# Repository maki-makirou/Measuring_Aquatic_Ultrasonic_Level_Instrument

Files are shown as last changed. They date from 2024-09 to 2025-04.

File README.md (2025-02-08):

# [Measuring Aquatic Ultrasonic Level Instrument (MAULI)](https://github.com/maki-makirou/Measuring_Aquatic_Ultrasonic_Level_Instrument)
Raspberry Pi Pico を用いた電子工作による**安価で高性能なロガー付き超音波式水位計**です。（1台約6,000円で作成できます。）　プログラムや部品を自由に変更して改造を楽しむことができます。

This is a low-cost, high-performance ultrasonic water level meter with logger that is electronically built using Raspberry Pi Pico. (One can be made for about 6,000 yen.) You can freely change the program and parts to have fun modifying it.

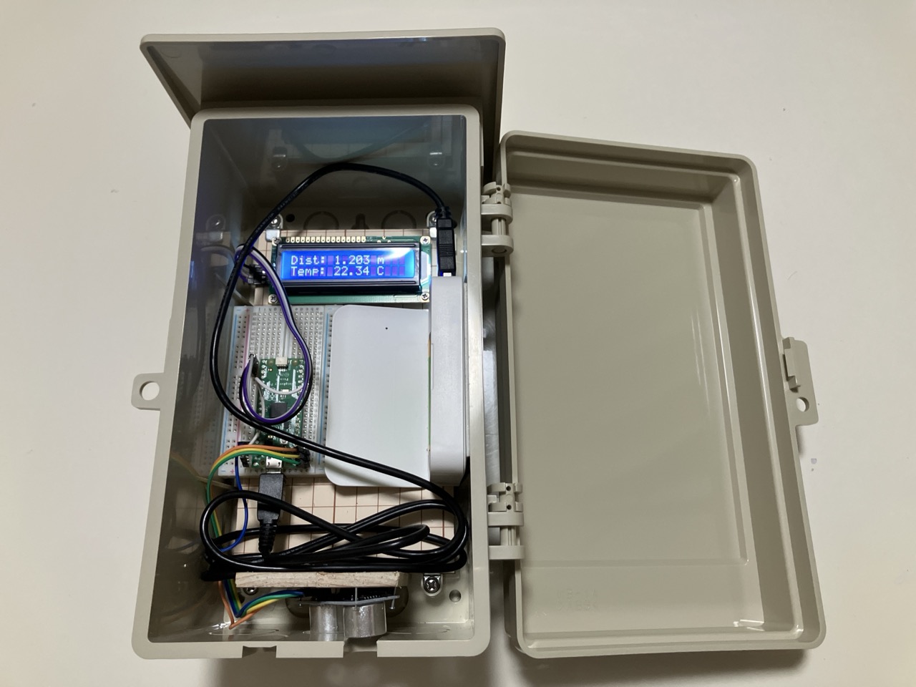
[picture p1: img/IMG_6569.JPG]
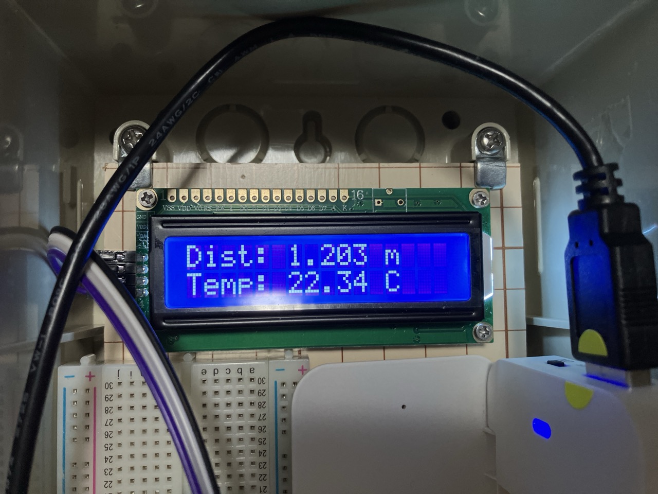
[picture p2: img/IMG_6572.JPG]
　　

<br>

## 特徴
- 主要コードは MicroPython で書かれたプログラマブル水位計です。目的に応じて測定間隔など様々なパラメータを変更することができます。プログラム自体も自由に変更できます。
- 1台約6,000円と安価に作成できます。（部品の送料、消耗品、工具等の費用を除く）
- Raspberry Pi Pico 内のメモリをロガーとしてcsv形式で計測値（水面までの距離、気温）を記録することができます。
- 超音波センサー（HC-SR04）の性能に基づき、0.3cm 程度の分解能の計測が可能です。（測定距離min: 0.02m、測定距離max: 4.5m、動作温度min: -10℃、動作温度max: 70℃、有効角度： 15度）　また、超音波の速度について Raspberry Pi Pico の内蔵温度計を使った温度補正を行っています。
- 超音波センサーを小型プラボックスに格納するため屋外での計測が可能です。雨天時の計測もできます。
- 故障した場合でも部品単位で修理が可能です。
- 異常値が出た時に自動的に設定した時間間隔、回数で再計測させることができます。
- 水位計測しない時間は lightsleep 状態となるため比較的長期間の連続観測が可能です。初期設定値（計測間隔1分、再計測最大2回、再計測10秒後）において、アルカリ単3電池3本で約5.2日間の連続計測ができます。アルカリ単1電池6本仕様に改造すれば約2ヶ月間（約59.6日間）の連続計測ができる見込みです。

<br>

## 短所
- 耐久性はあまりないと思われます。
- DIY水位計のため、組み立てが面倒です。
- 最大測定距離が4.5mしかないため、大河川などには向きません。
- 超音波センサーの有効角度が15度であるため、複雑な横断形状の小水路などには向きません。（センサーが水面以外の反射を拾ってしまうため）
- RTCを使用していないため日時が記録されません。記録開始日時をメモしてデータ回収後、自分で日時補正する必要があります。
- 超音波センサーから水面までの計測距離がロガーに記録されるため、自分で水位に変換する必要があります。
- 水位計の設置位置によってはノイズが出ることがあります。（設置やパラメータの変更で改善させることができます。）　一方、大雨時はノイズが出にくいので高水観測に向いています。
- 使用部品の仕様が変更された場合、正しく動作させるために配線やコードの修正が必要になる可能性があります。

<br>

## ライセンス
- 作者が作成した python コードは MIT ライセンスに従って自由に改変することが出来ます。
- 作者以外の方が作成したコードについては、以下の通り各作者の主張するライセンスに従う必要があります。
  - 内蔵温度計から温度を取得する[コード](https://github.com/raspberrypi/pico-micropython-examples/blob/master/adc/temperature.py)の著作権は Raspberry Pi Ltd. にあります。ライセンスは [LICENSE.txt](https://github.com/raspberrypi/pico-micropython-examples/blob/master/LICENSE.txt)に従う必要があります。
  - LCD関係のコードの著作権は Tyler Peppy(T-622) 氏にあります。https://github.com/T-622/RPI-PICO-I2C-LCD
  - 超音波センサーの値取得に関するコードは広く使われているものですが出典が不明です。自己責任でご使用ください。情報をお持ちの方は [Discussions](https://github.com/maki-makirou/Measuring_Aquatic_Ultrasonic_Level_Instrument/discussions) にお願いします。

<br>

## 作り方
以下のリンク先をご覧ください。
- [2025年1月版](https://github.com/maki-makirou/Measuring_Aquatic_Ultrasonic_Level_Instrument/blob/main/MAULI_202501/MAULI_202501.md)

<br>

## 使い方
### 設置時
1. **水位観測における失敗の殆どが水位計の設置ミスに起因**するものです。予め十分に練習してコツを掴んでおいてください。
- **超音波の有効角度が15度であることを踏まえ、超音波が不要なもの（構造物や植物等）に当たらないように（水面だけに当たるように）水位計を設置**してください。
- **水位計は水深が変化しない地点に設置**してください。

2. 初期設定では、**電源を入れて1分間は計測値が液晶ディスプレイに表示されるスタートモード**になり、**1分後以降はログ記録モードになり測定値を内部メモリに1分間隔で記録します**。電池をセットし、時計を見ながら 00 秒ちょうどに電源を入れてください。**1分後の時刻を忘れずにメモしてください。**

3. **水位計の設置地点の水深をmm単位で測り、忘れずにメモしておいてください。**

4. 屋外で使用する場合は、風等の衝撃で電池が外れることがあります。**電池が外れないように必ずセロハンテープ等で固定してください。**

5. **南京錠等でフタが開かないようにしてください。**

<br>

### データ回収時
1. 水位計を回収したら　PC に接続して Thonny を起動して、右上の「STOP」ボタンを押した後、ラズパイ pico 内の「log.csv」ファイルを開いてデータをコピーしてください。Thonny の使い方は他のサイトで調べてください。

2. 表計算ソフトを立ち上げてコピーしたデータをペーストして一旦保存してください。

3. メモした記録開始時間と水深データを使って、水位の時刻変化のデータに変換してください。ロガーに記録されている 「Distance(m)」 は超音波センサー先端から水面までの距離を記録したものですので水位への変換が必要です。

4. 無事にデータを水位に変換できたら、次の測定のために Thonny でラズパイ pico 内の「log.csv」ファイルを右クリックして「Delete」してください。

<br>

## 改造について
大容量の電池を使用できるようになればより実用的になります。[このサイト（単1電池6本版）](https://github.com/maki-makirou/Measuring_Aquatic_Ultrasonic_Level_Instrument_Mod)をご参考ください。
また、水位計を wifi 対応にしてIoT機器化したい場合は、[このサイト](https://github.com/maki-makirou/RPI-RP2_genkan_mimamoru_kun)のコードが参考になるかもしれません。
他にもSDカード対応にしたり、ソーラー電源を付けたり、Bluetooth対応にしたり、アイディア次第で様々な発展形が考えられます。
なお、改造についても自己責任となりますので、リスクを理解した上で楽しんでください。

<br>

## 注意点
屋外設置の際は、土地所有者や水路管理者の許可が必要です。**許可なく水位計を設置しないようご注意ください。**

<br>

## ノウハウ
使用上のノウハウを[ここ](https://github.com/maki-makirou/Measuring_Aquatic_Ultrasonic_Level_Instrument/blob/main/Know-how/Know-how.md)にまとめました。

<br>

## 問い合わせ先
  [Discussions](https://github.com/maki-makirou/Measuring_Aquatic_Ultrasonic_Level_Instrument/discussions) で問い合わせてください。

<br>

## 謝辞
Raspberry Pi財団の皆様と電子部品やプラボックス等を供給してくださるメーカーの皆様に感謝します。最後に私の妻に感謝します。

<br>

## 履歴
- 2024-12-22 公開

<br>

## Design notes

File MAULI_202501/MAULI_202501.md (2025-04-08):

# Measuring Aquatic Ultrasonic Level Instrument (MAULI) の作り方 (2025年1月版)
Raspberry Pi Pico を用いた電子工作による安価で高性能なロガー付き超音波式水位計の作り方です。

<br>

## 部品等
### 部品リスト
使用した部品と購入先のリンクをまとめました。**一見同じ製品に見えても仕様が異なるものがあります。リンク先のものを購入することを強くおすすめします。**

|No|購入先|部品名（購入先リンク）|価格|確認年月|備考|
|---|---|---|---:|---|---|
|1|スイッチサイエンス|[Raspberry Pi Pico H](https://www.switch-science.com/collections/raspberry-pi/products/8170)|¥1,012|2024/10||
|2|秋月電子通商|[HC-SR04　超音波センサー](https://akizukidenshi.com/catalog/g/g111009/)|¥300|2024/10|2020年型であること|
|3|秋月電子通商|[ブレッドボード BB-801](https://akizukidenshi.com/catalog/g/g105294/)|¥220|2024/10||
|4|秋月電子通商|[USBケーブル USB2.0 Aオス-マイクロBオス 1.5m A-microB](https://akizukidenshi.com/catalog/g/g107607/)|¥170|2024/10||
|5|Amazon|[Freenove I2C LCD 1602モジュール、新しいタイプIIC TWIシリアル16x2ディスプレイ](https://www.amazon.co.jp/Freenove-1602%E3%83%A2%E3%82%B8%E3%83%A5%E3%83%BC%E3%83%AB%E3%80%81%E6%96%B0%E3%81%97%E3%81%84%E3%82%BF%E3%82%A4%E3%83%97IIC-TWI%E3%82%B7%E3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)|¥1,080|2024/10|新型であること。2個入りの方が安いです。|
|6|Amazon|[未来工業(MIRAI) ウオルボックス 屋根付・タテ型 有効フカサ90 ベージュ 1個 WB-1AJ](https://www.amazon.co.jp/%E6%9C%AA%E6%9D%A5%E5%B7%A5%E6%A5%AD-%E3%82%A6%E3%82%AA%E3%83%AB%E3%83%9C%E3%83%83%E3%82%AF%E3%82%B9-%E5%B1%8B%E6%A0%B9%E4%BB%98%E3%83%BB%E3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)|¥1,835|2024/10|[楽天市場でも購入できます](https://item.rakuten.co.jp/denzaido/4571359794828/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)|
|7|Amazon|[KKHMF 3PCS 120本 20cm ブレッドボード・ジャンパーワイヤ 回路基板のジャンパーピン（メス-オス）](https://www.amazon.co.jp/KKHMF-40%E6%9C%AC-20cm-%E3%83%96%E3%83%AC%E3%83%83%E3%83%89%E3%83%9C%E3%83%BC%E3%83%89%E3%83%BB%E3%82%B8%E3%83%A3%E3%83%B3%E3%83%91%E3%83%BC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)|¥699|2024/10|※1|
|8|Amazon|[3M 両面テープ 超強力 スーパー多用途 幅12mm 長さ4m スコッチ SPS-12 セミロング プレミアゴールド](https://www.amazon.co.jp/3M-%E3%82%B9%E3%83%AA%E3%83%BC%E3%82%A8%E3%83%A0-SPS-12-%E3%82%B9%E3%82%B3%E3%83%83%E3%83%81%E8%B6%85%E5%BC%B7%E5%8A%9B%E4%B8%A1%E9%9D%A2%E3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)|¥752|2024/10|※1|
|9|Amazon|[ボンド ウルトラ多用途S・U プレミアムソフト クリヤー 25ml](https://www.amazon.co.jp/%E3%82%A6%E3%83%AB%E3%83%88%E3%83%A9%E5%A4%9A%E7%94%A8%E9%80%94S%E3%83%BBU-%E3%83%97%E3%83%AC%E3%83%9F%E3%82%A2%E3%83%A0%E3%82%BD%E3%83%95%E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)|¥584|2024/10|※1|
|10|ヒラキ|[乾電池式モバイルバッテリー](https://www.hiraki.co.jp/ec/pro/disp/1/53128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)|¥638|2024/10||
|11|スーパービバホーム|桧工作材　5x30x900|¥408|2024/10|最終的に必要なサイズは 5x60x80 です。[写真](https://github.com/maki-makirou/Measuring_Aquatic_Ultrasonic_Level_Instrument/blob/main/MAULI_202501/Woodworking/img/IMG_4892.JPG)　※1|
|12|スーパービバホーム|ピン釘（20x13mm）|¥138|2024/11|[写真](https://github.com/maki-makirou/Measuring_Aquatic_Ultrasonic_Level_Instrument/blob/main/MAULI_202501/Woodworking/img/IMG_6449.JPG)　※1|
|13|スーパービバホーム|ステンレス建具用木ねじ皿（2x19mm）|¥228|2024/11|[写真](https://github.com/maki-makirou/Measuring_Aquatic_Ultrasonic_Level_Instrument/blob/main/MAULI_202501/Woodworking/img/IMG_6419.JPG)　※1|
|14|スーパービバホーム|ピン釘（20x19mm）|¥138|2024/11|[写真](https://github.com/maki-makirou/Measuring_Aquatic_Ultrasonic_Level_Instrument/blob/main/MAULI_202501/Woodworking/img/IMG_6335.JPG)　※1|

<br>

※1 量が多いので、2台目以降を製作する場合は当分の間、追加購入は不要です。1台目製作時は購入してください。

<br>

#### ！！！　注意点　！！！
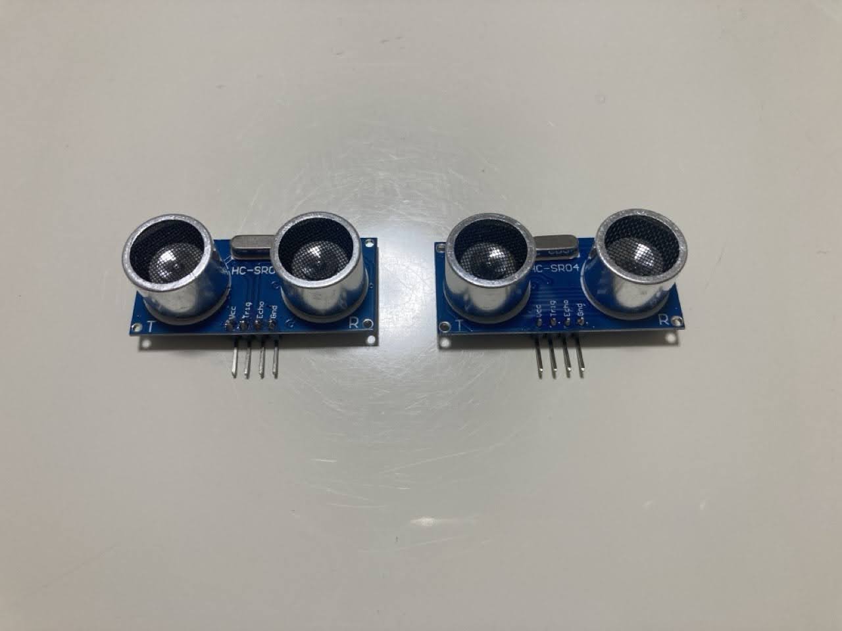
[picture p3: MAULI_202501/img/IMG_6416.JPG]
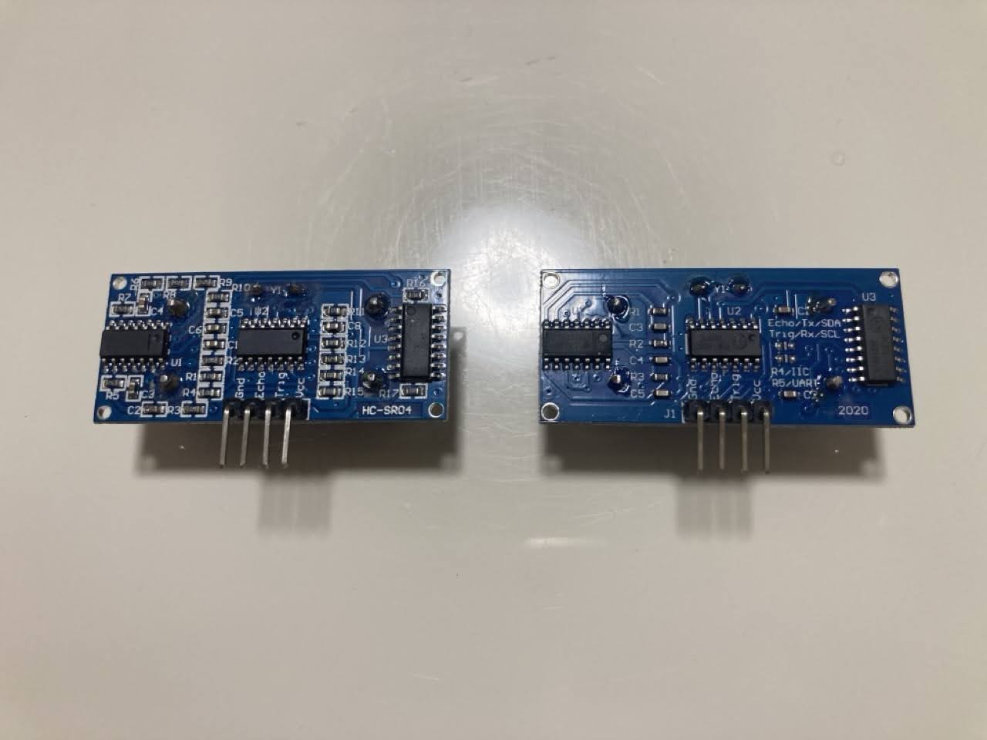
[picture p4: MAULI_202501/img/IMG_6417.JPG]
　　

超音波センサーについて、右側が3.3V仕様の2020年型です。左側は5V仕様のもので今回の配線では動きません。似ているのでご注意ください。リンク先のものを購入することをおすすめします。

<br>

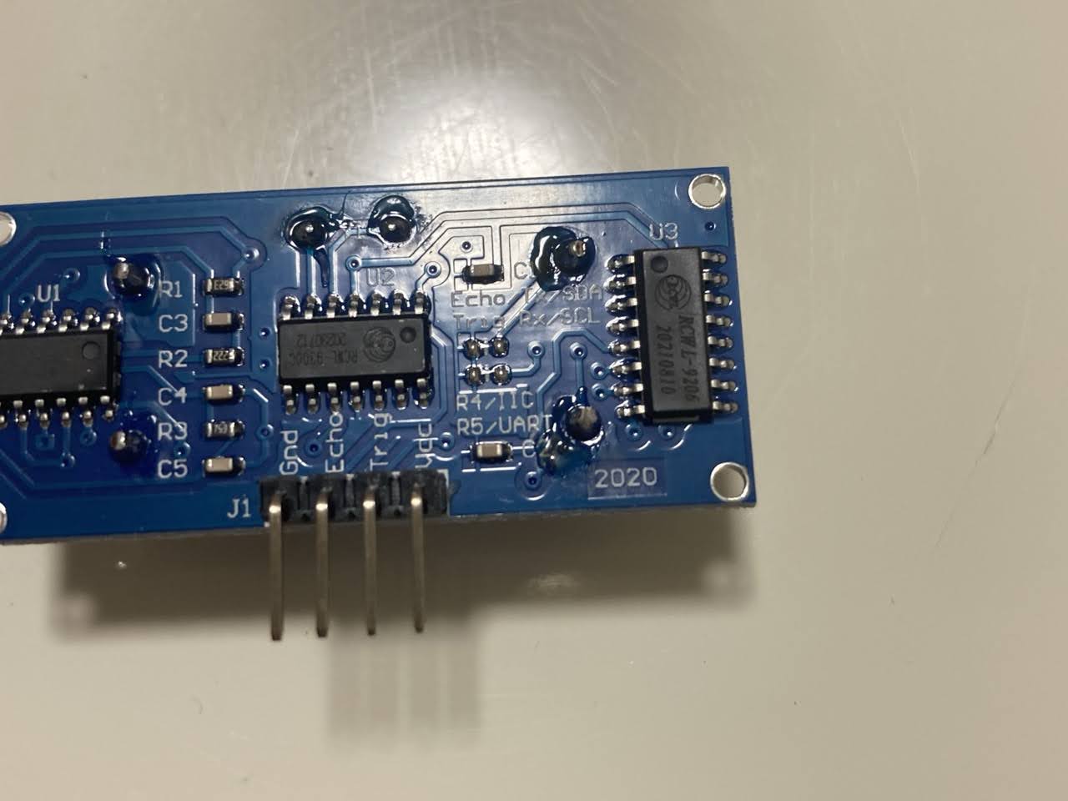
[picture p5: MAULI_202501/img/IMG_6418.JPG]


2020年型は基板の右下に「2020」がプリントされています。
もし、5V仕様のものを間違えて購入した場合は、例えば[この配線図](https://github.com/maki-makirou/Measuring_Aquatic_Ultrasonic_Level_Instrument/blob/main/MAULI_202501/img/202210_B.png)
のようにして、下の方にある[このコード](https://github.com/maki-makirou/Measuring_Aquatic_Ultrasonic_Level_Instrument/blob/main/MAULI_202501/MAULI_20250113.py)の一部を上段から下段に変えると使用できます。

```
# Old
trigger = Pin(0, Pin.OUT)
echo = Pin(1, Pin.IN)
led = Pin(25, Pin.OUT)
i2c = I2C(0, sda = Pin(16), scl = Pin(17), freq = 400000)
```

```
# New
trigger = Pin(14, Pin.OUT)
echo = Pin(15, Pin.IN)
led = Pin(25, Pin.OUT)
i2c = I2C(0, sda = Pin(0), scl = Pin(1), freq = 400000)
```

<br>

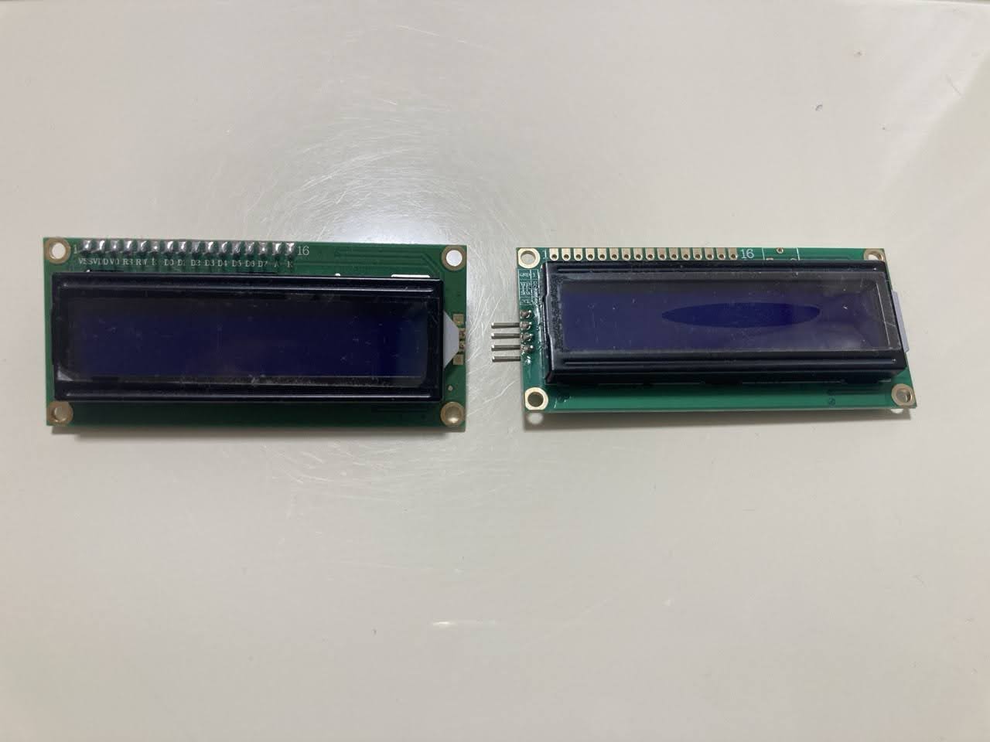
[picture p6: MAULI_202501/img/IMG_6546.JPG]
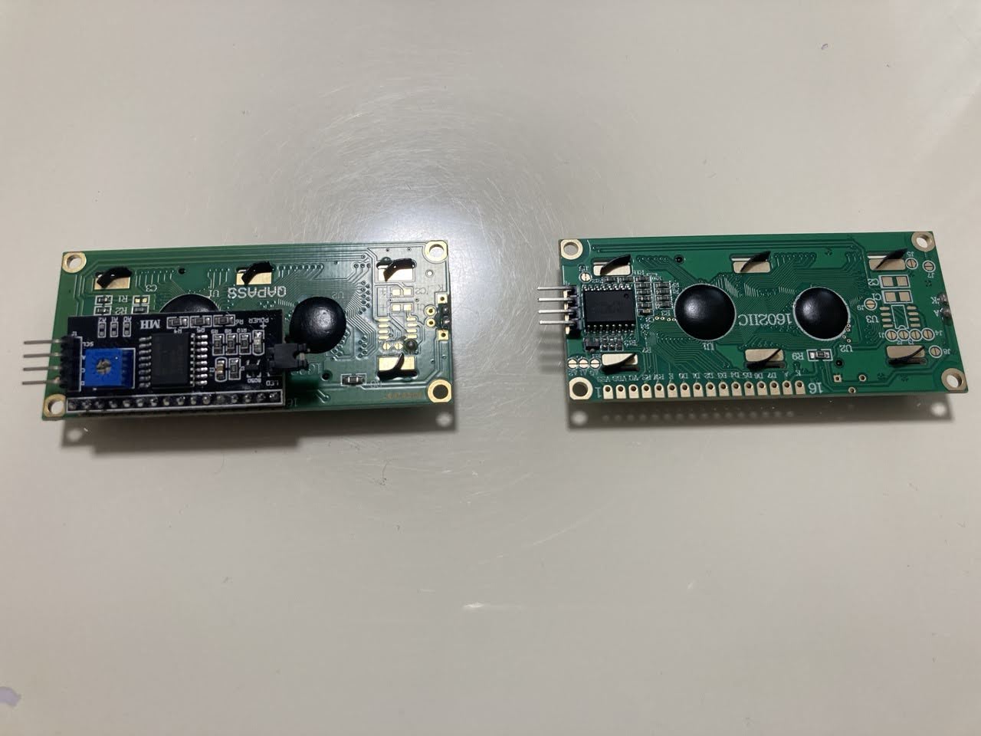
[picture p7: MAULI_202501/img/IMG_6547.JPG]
　　

LCDについて右側が新型です。左側の旧型でも動きますが、はんだ付けが必要な製品が多いのでご注意ください。リンク先のものを購入することをおすすめします。

<br>

### 一般材料リスト
- 単3乾電池3本（アルカリでもマンガンでも可）
- 木工ボンド
- 爪楊枝
- セロハンテープ
- 南京錠等
- シール（お好みで）

<br>

### 工具等
- ニッパー
- 金槌
- カッター
- ラジオペンチ
- 鉛筆等

<br>

### その他
- パソコン

<br>

## 作り方
### はじめに
[このサイト](https://osoyoo.com/ja/2021/07/14/raspberry-pi-pico-learning-kit-lesson-1-getting-started-with-micropython/)などを参考にして、PC に Thonny をインストールして動作確認してください。また、[ファームウェア(RPI_PICO-20240602-v1.23.0.uf2)](https://github.com/maki-makirou/Measuring_Aquatic_Ultrasonic_Level_Instrument/blob/main/MAULI_202501/RPI_PICO-20240602-v1.23.0.uf2)を[ここから](https://micropython.org/download/RPI_PICO/)入手してUSBケーブルを繋いで Raspberry Pi Pico に書き込んでください。

<!---
#（サンプルコード [Lチカ](https://github.com/maki-makirou/Measuring_Aquatic_Ultrasonic_Level_Instrument/blob/main/MAULI_202501/L_Chika.py)）
-->

### 配線
配線図の通りにブレッドボードに Raspberry Pi Pico を差し込んで、ディスプレイ（LCD1602I2C）と超音波センサー（HC-SR04）をジャンパワイヤーで繋いでください。

<br>

|部品|機能|接続先|No.|ブレッドボードNo.|
|---|---|---|--|--|
|HC-SR04|VCC|3V3|36|右5|
|HC-SR04|TRIG|GP0|1|左1|
|HC-SR04|ECHO|GP1|2|左2|
|HC-SR04|GND|GND|3|左3|
|LCD1602I2C|GND|GND|23|右18|
|LCD1602I2C|VCC|VBUS|40|右1|
|LCD1602I2C|SDA|GP16|21|右20|
|LCD1602I2C|SCL|GP17|22|右19|

<br>

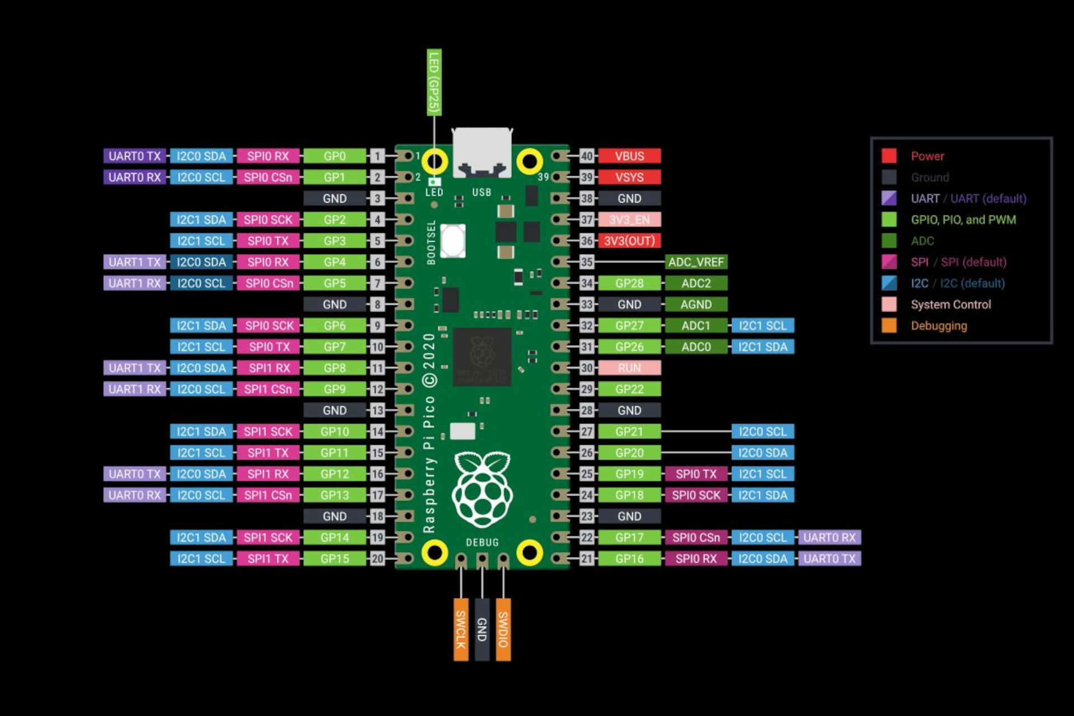
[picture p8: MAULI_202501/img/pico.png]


Raspberry Pi Pico ピンレイアウト

<br>

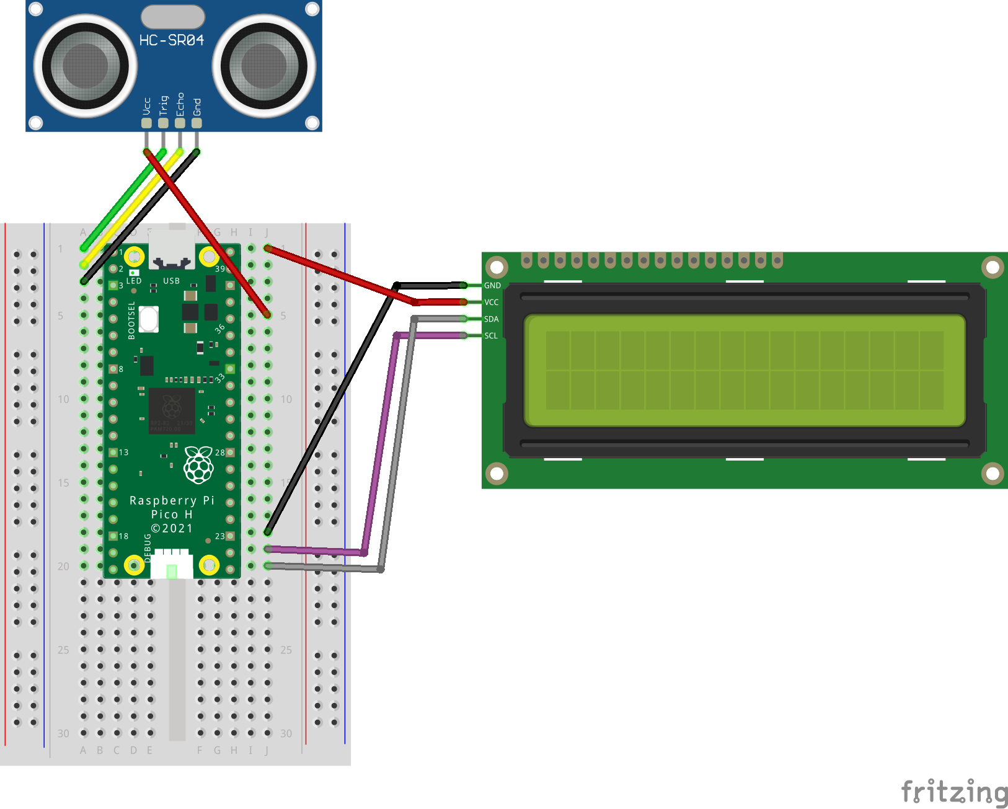
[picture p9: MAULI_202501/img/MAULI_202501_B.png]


配線図

<br>

[Frizingファイル](https://github.com/maki-makirou/Measuring_Aquatic_Ultrasonic_Level_Instrument/tree/main/MAULI_202501/MAULI_202501.fz)

<br>

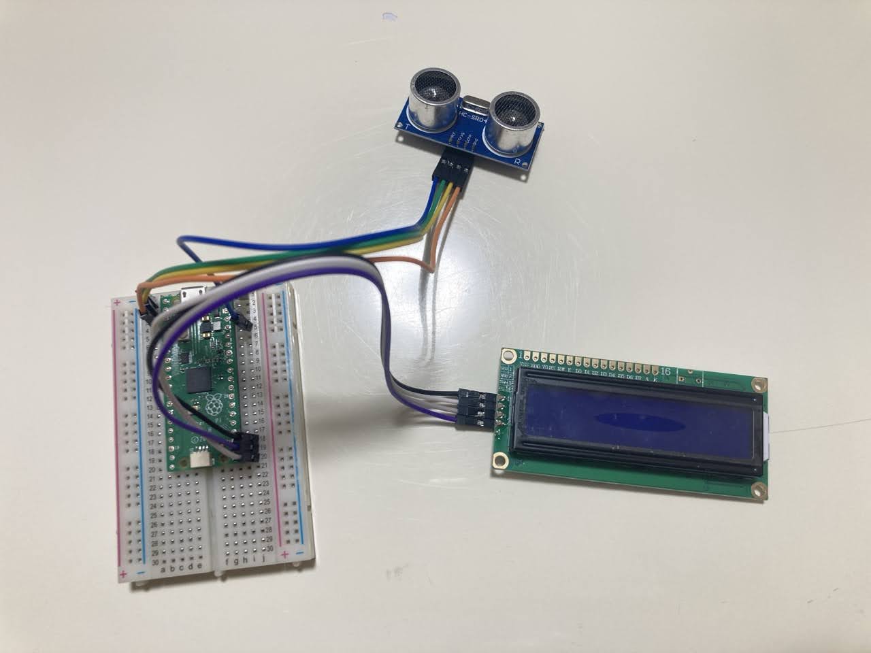
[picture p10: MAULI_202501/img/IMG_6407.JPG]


配線作業完了後、このようになります。**ここで接着剤（ボンド ウルトラ多用途S・U プレミアムソフト クリヤー 25ml）でワイヤーをブレッドボードに差し込んだ箇所を固定すると風等の衝撃で抜けにくくなります。**

<br>

### プログラム
以下のコードをThonny で開いてください。

[MAULI_20250113.py (Ver.0.9.0)](https://github.com/maki-makirou/Measuring_Aquatic_Ultrasonic_Level_Instrument/blob/main/MAULI_202501/MAULI_20250113.py)

コードを修正する際は、Thonny でパラメータ `POWER_SAVING_MODE = 0` にしてください。
これは2箇所ある省電力モード指定を lightsleepモードにするか sleepモードにするか選択するパラメータです。
`POWER_SAVING_MODE = 0`にすると sleepモードになり、通常の sleep命令を実行します。
`POWER_SAVING_MODE = 1`にすると消費電力が少ない lightsleep命令を実行します。
`machine.lightsleep`が実行されている間は赤色の「STOP」ボタンを受け付けなくなったり、PC が Raspberry Pi Pico を見失ってエラーが出たりします。
`machine.lightsleep`は待機電力を少なくするための重要なスリープ命令です。デバッグが終わり外部バッテリーを使用する際は、`SAVING_MODE = 1`に戻してください。

```
# Turn on or turn off the power saving mode
POWER_SAVING_MODE = 1    # 0: OFF, 1: ON
```

<br>

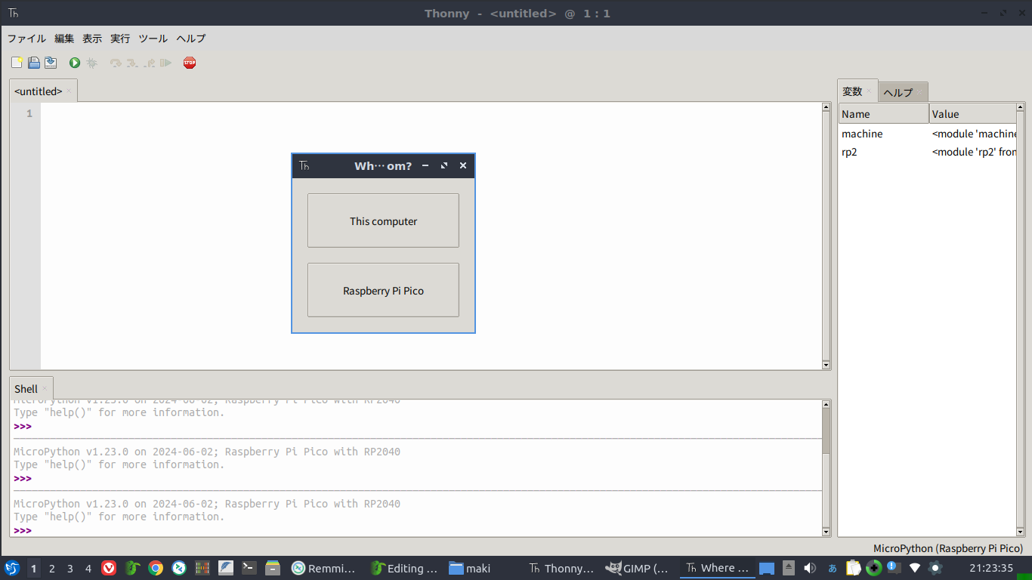
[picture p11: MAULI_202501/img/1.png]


Raspberry Pi Pico を接続後、「ファイル」-「Open」を選択して、画面下の「Raspberry Pi Pico」を押してください。但し、**既に Raspberry Pi Pico 内に main.py がある場合は「ヘルプ」の下にある赤い「STOP」ボタンを押してください。通電すると自動的に main.py が起動し測定モードに入ってしまうためプログラムを停止する必要があります。**

<br>

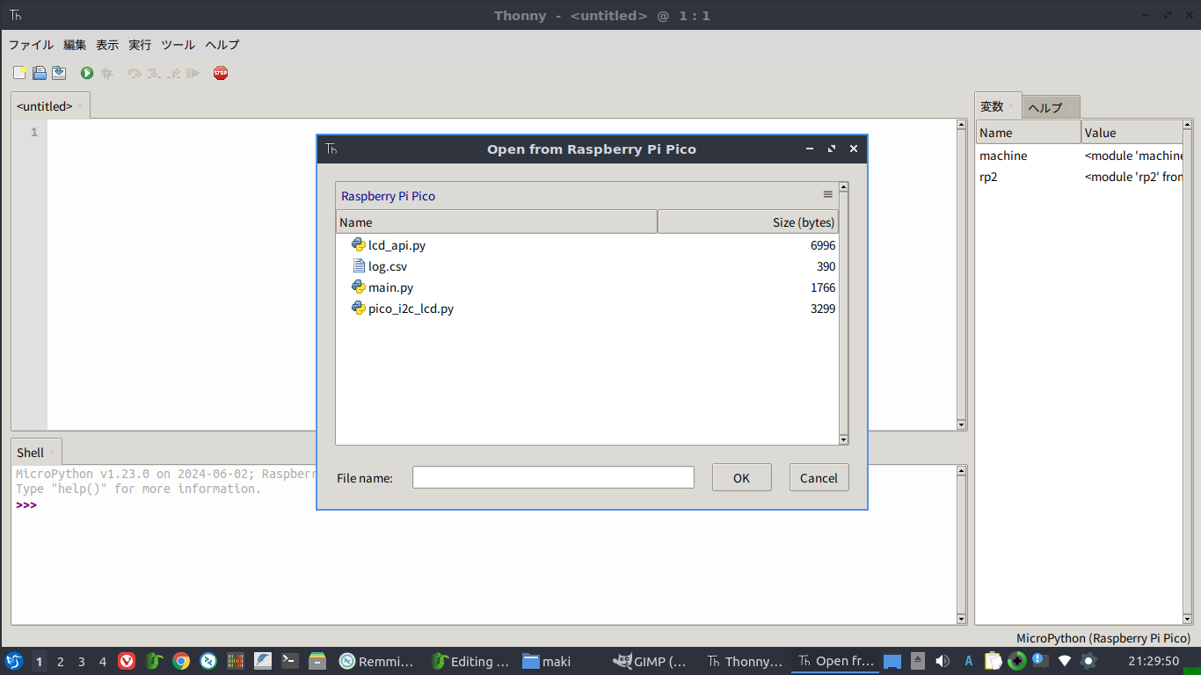
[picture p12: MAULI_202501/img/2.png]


今開いているコードを main.py にリネームして「Raspberry Pi Pico」フォルダの直下に書き込んでください。
また、[このサイト](https://github.com/T-622/RPI-PICO-I2C-LCD)から、[lcd_api.py](https://github.com/maki-makirou/Measuring_Aquatic_Ultrasonic_Level_Instrument/blob/main/MAULI_202501/lcd_api.py) と [pico_i2c_lcd.py](https://github.com/maki-makirou/Measuring_Aquatic_Ultrasonic_Level_Instrument/blob/main/MAULI_202501/pico_i2c_lcd.py) をそれぞれ取得して同じ名前（lcd_api.py，pico_i2c_lcd.py）で Raspberry Pi Pico 内部の main.py と同じフォルダに置いてください。

正常な場合は、画面のようになります。**但し、初回起動時は log.csv はありません。一度計測すると log.csv が現れます。** なお、追記モードでデータを書き込むため、繰り返し測定しても自分で消さない限り過去取得したデータは消えません。

<br>

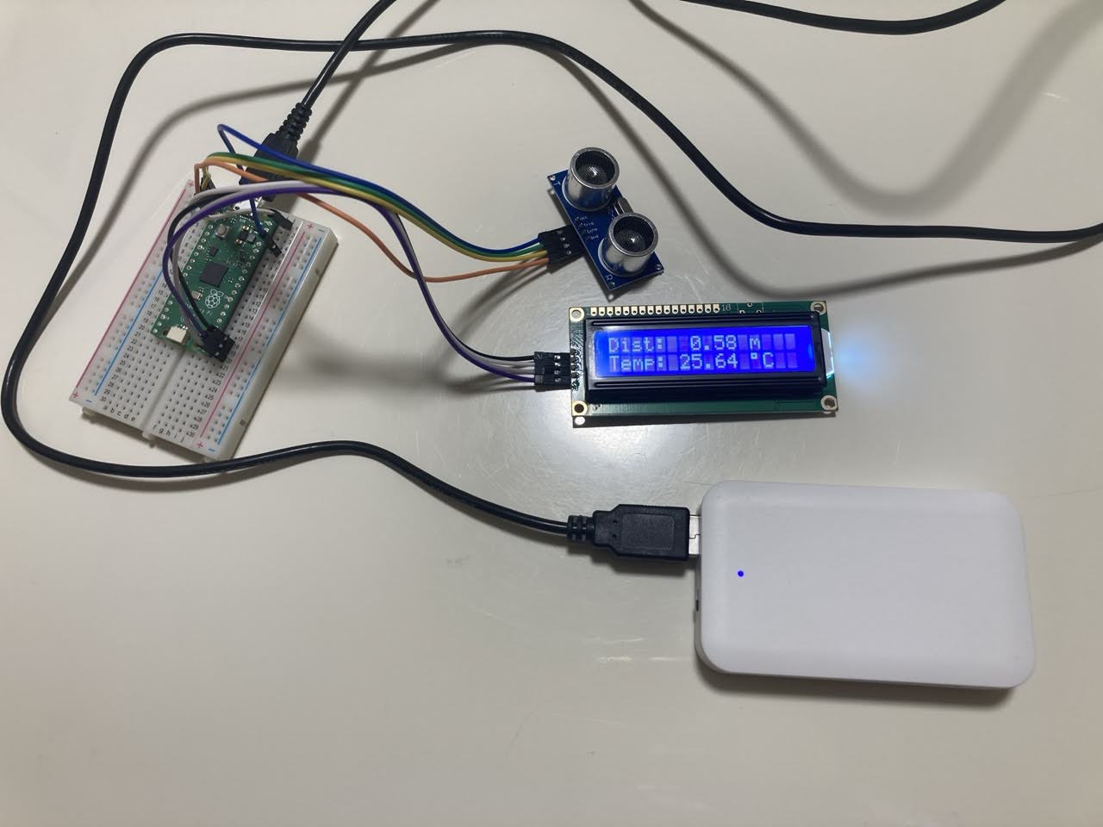
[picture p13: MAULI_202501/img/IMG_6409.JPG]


PCから Raspberry Pi Pico を外してバッテリーを接続してください。うまく動くとこのようになります。

<br>

### プラボックス組み込み
以下の手順で水位計をプラボックスに組み込んでください。

1. [プラボックス加工](https://github.com/maki-makirou/Measuring_Aquatic_Ultrasonic_Level_Instrument/blob/main/MAULI_202501/Plastic_box/Plastic_box.md)

2. [木工作業](https://github.com/maki-makirou/Measuring_Aquatic_Ultrasonic_Level_Instrument/blob/main/MAULI_202501/Woodworking/Woodworking.md)

<br>

屋外に設置する際は、風の衝撃等で蓋が空いてしまうので、**必ず左側の蓋と本体を合わせる穴に南京錠などを付けてください。**

お疲れ様でした！！

<br>

[戻る](https://github.com/maki-makirou/Measuring_Aquatic_Ultrasonic_Level_Instrument/tree/main)

<br>

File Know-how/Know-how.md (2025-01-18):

# Measuring Aquatic Ultrasonic Level Instrument (MAULI) に関するノウハウ
Measuring Aquatic Ultrasonic Level Instrument (MAULI) に関するノウハウをまとめます。

<br>

## 1. 電池外れ防止対策
屋外で使用する場合は、風等の衝撃で電池が外れることがあります。**電池が外れないように必ずセロハンテープ等で固定してください。**
結構外れるので注意してください。

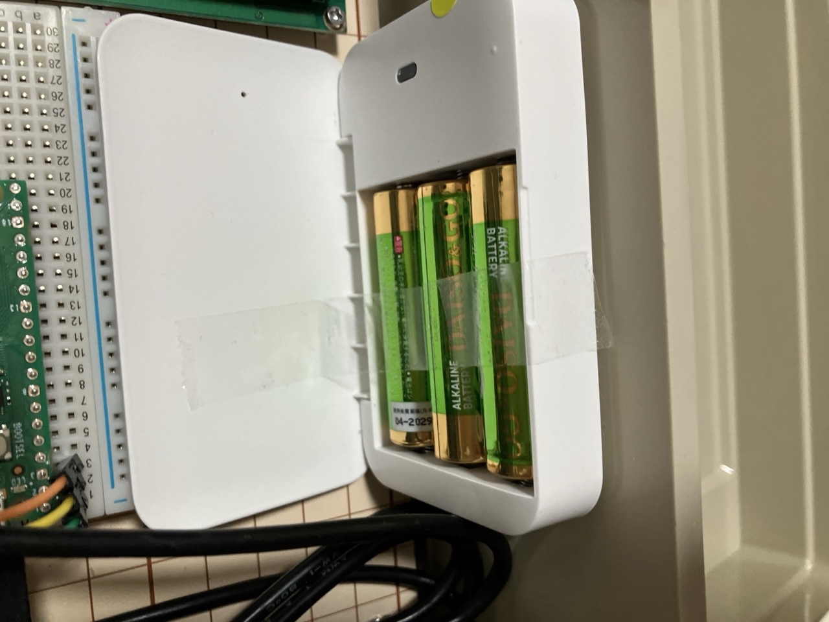
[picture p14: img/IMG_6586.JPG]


<br>

## 2. 南京錠等によるフタの固定
**南京錠等でフタが開かないようにしてください。**
忘れると設置できないので、水位計と一緒に保管しておくのがいいかもしれません。

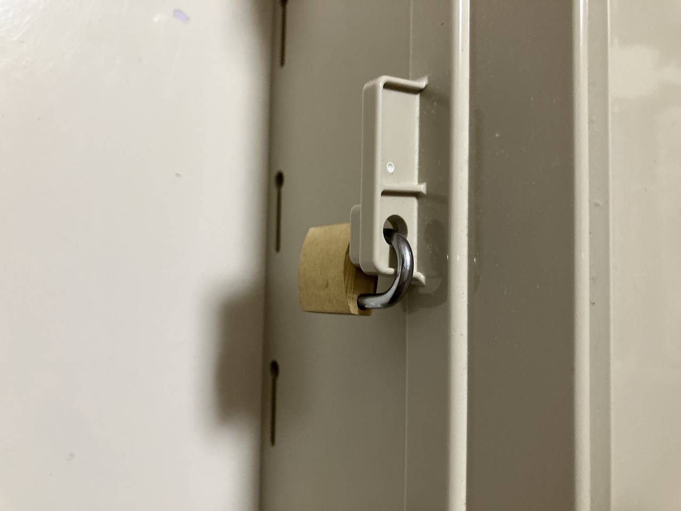
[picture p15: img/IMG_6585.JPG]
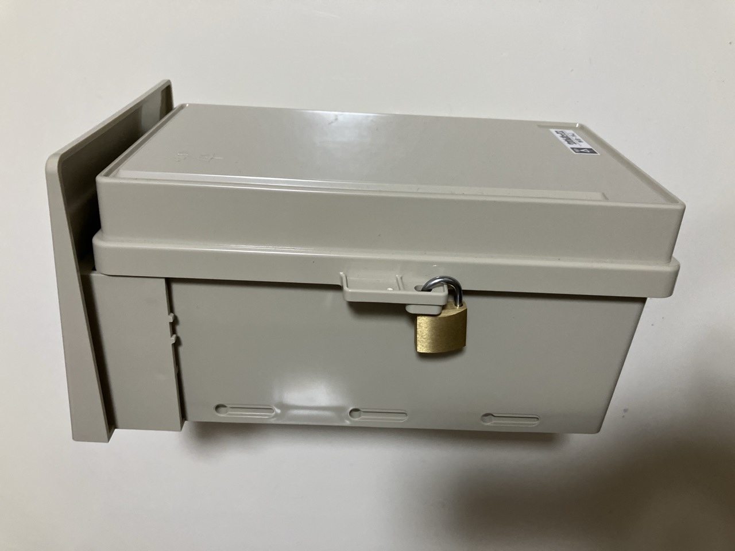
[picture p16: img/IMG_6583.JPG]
　　

<br>

## 3. ワイヤー抜け対策
ワイヤーがブレッドボードに刺さった箇所を接着剤（ボンド ウルトラ多用途S・U プレミアムソフト クリヤー 25ml）で固定すると風等の衝撃で抜けにくくなります。
ちょうどよい接着力で接着後もきれいに剥がすことができます。メンテナンス性が高いのでおすすめです。

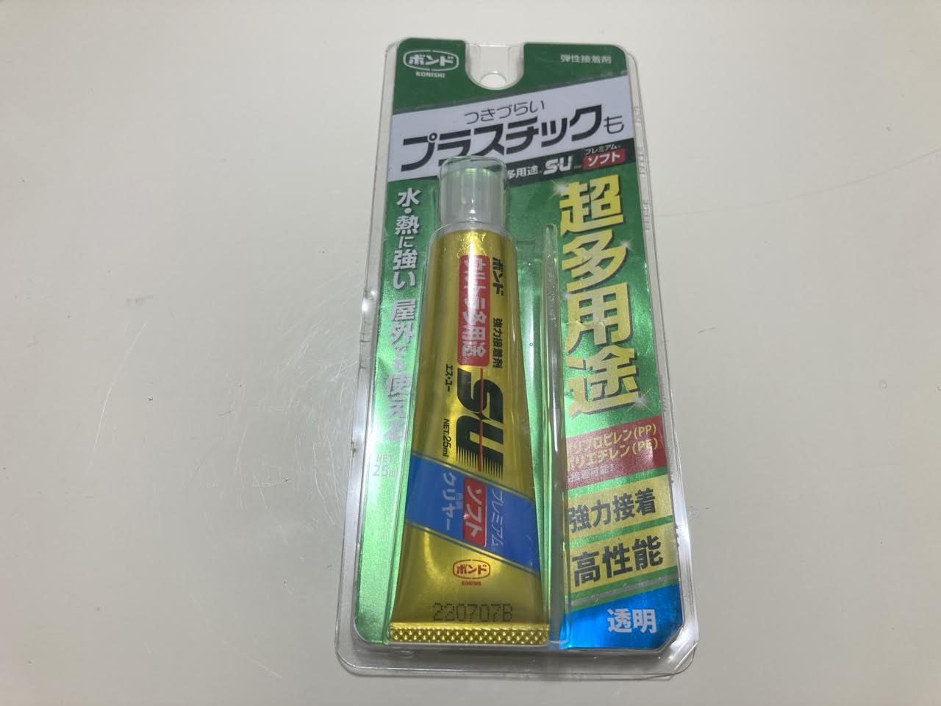
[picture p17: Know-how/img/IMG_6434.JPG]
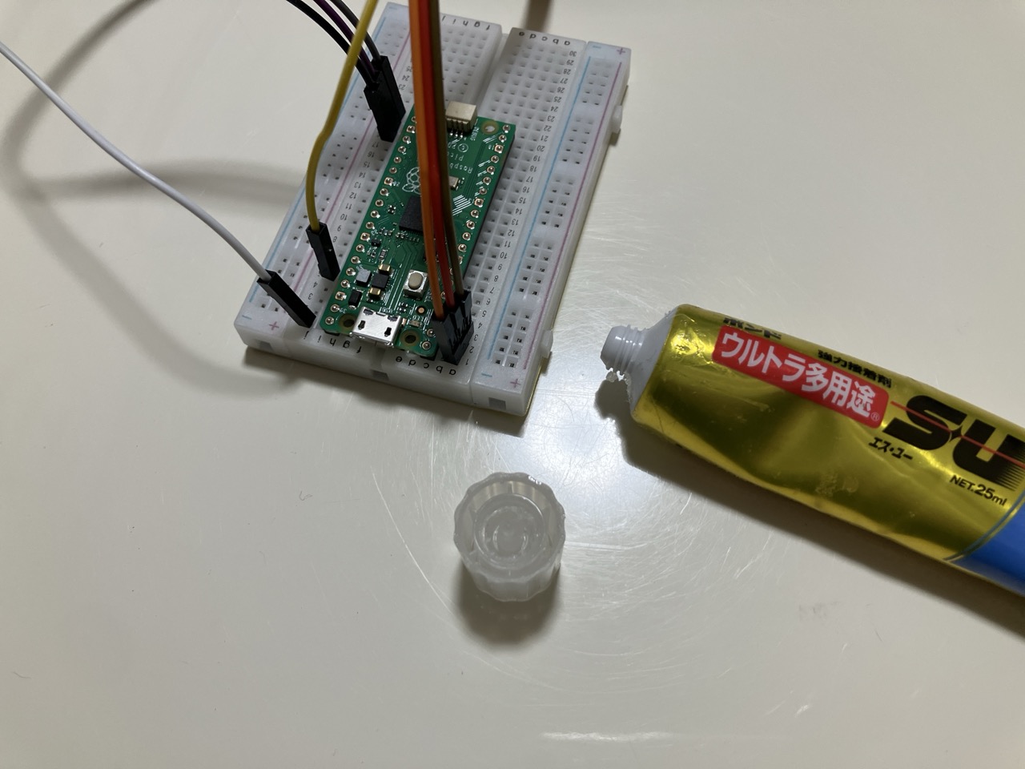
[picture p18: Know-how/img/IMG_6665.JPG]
　　

<br>

接着力塗布前後の写真です。

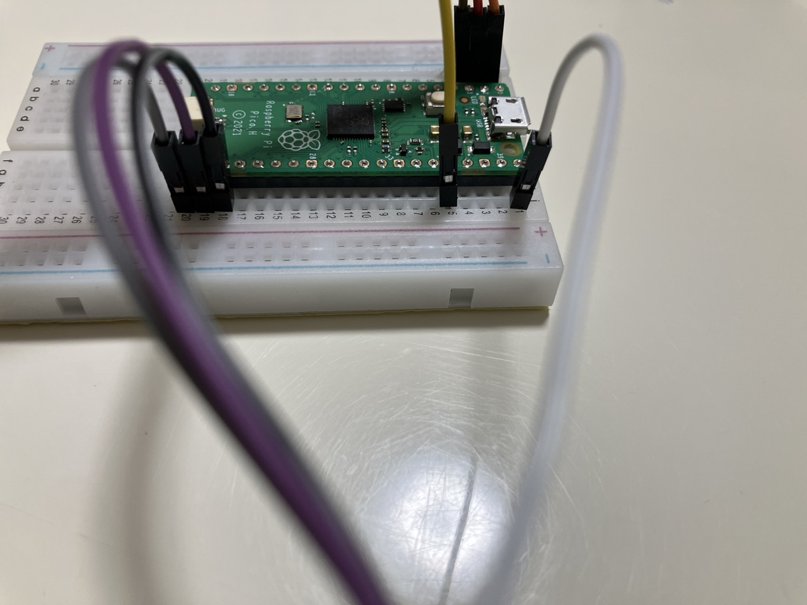
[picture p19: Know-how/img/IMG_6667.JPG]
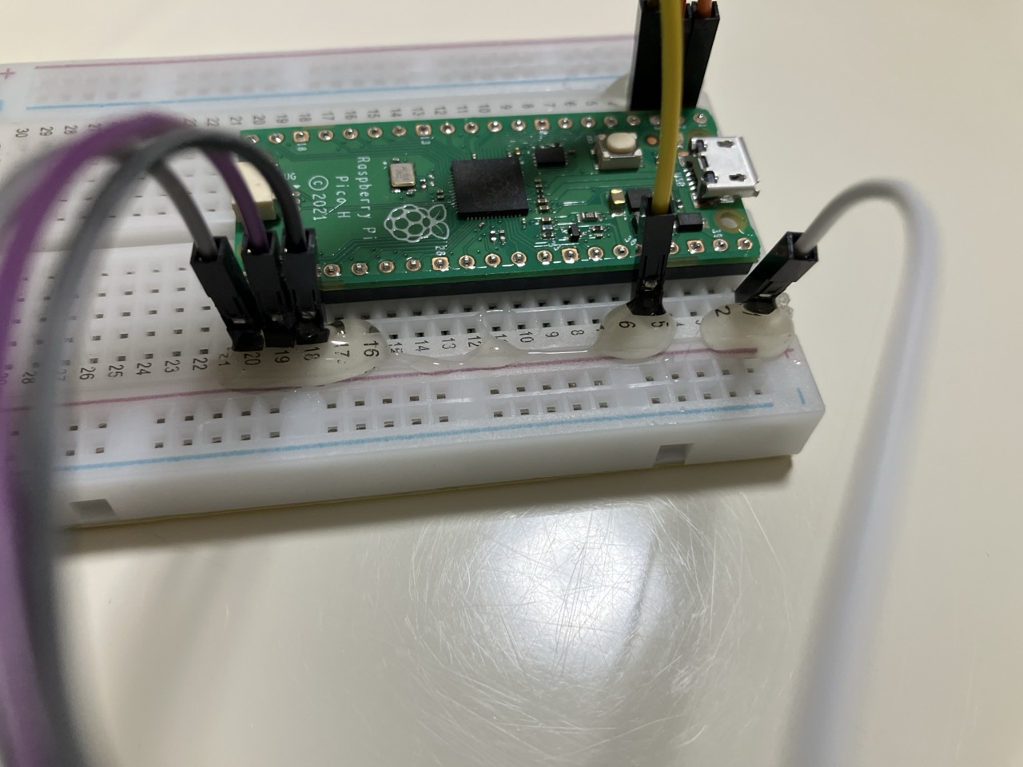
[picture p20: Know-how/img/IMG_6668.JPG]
　　

<br>

## 4. プラボックスの固定方法について
以下の市販のネジ等の組み合わせでプラボックスを固定することが可能です。これにより取付の自由度が高まります。

|No|購入先|部品名（購入先リンク）|価格|確認月|備考|
|---|---|---|---:|---|---|
|1|スーパービバホーム|ステンレス　タッピング　なべ　5x12mm|¥178|2024/11||
|2|スーパービバホーム|ステンレス　丸座金　5x12mm|¥168|2024/11||
|3|スーパービバホーム|ステンレス　ばね座金　5mm|¥130|2024/11||

<br>

ネジの写真です。寸法があっていれば他の材質でもいいと思いますが、屋外設置を考えてステンレス製を選びました。

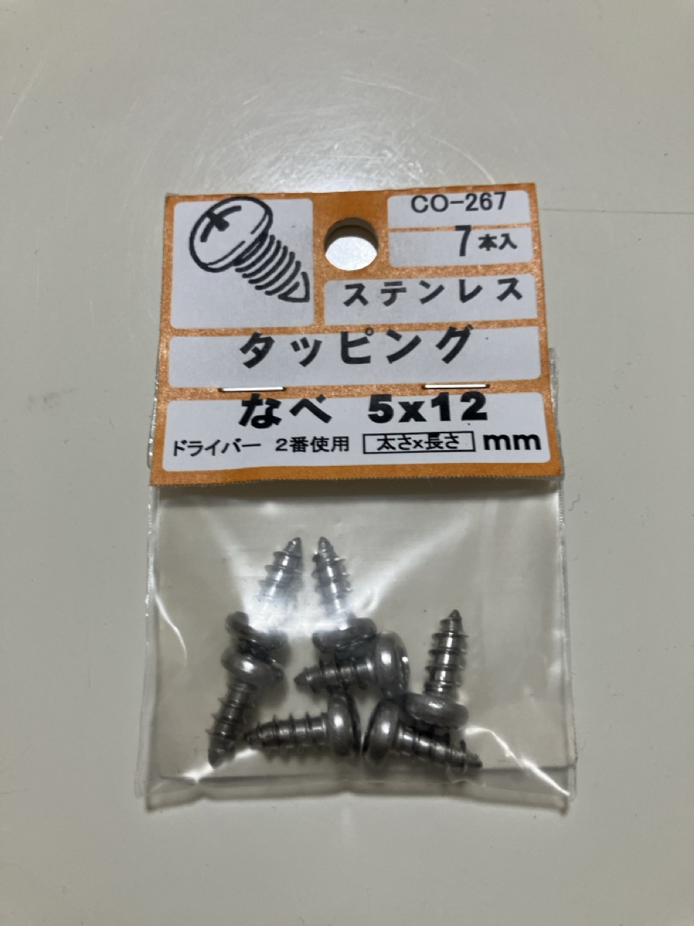
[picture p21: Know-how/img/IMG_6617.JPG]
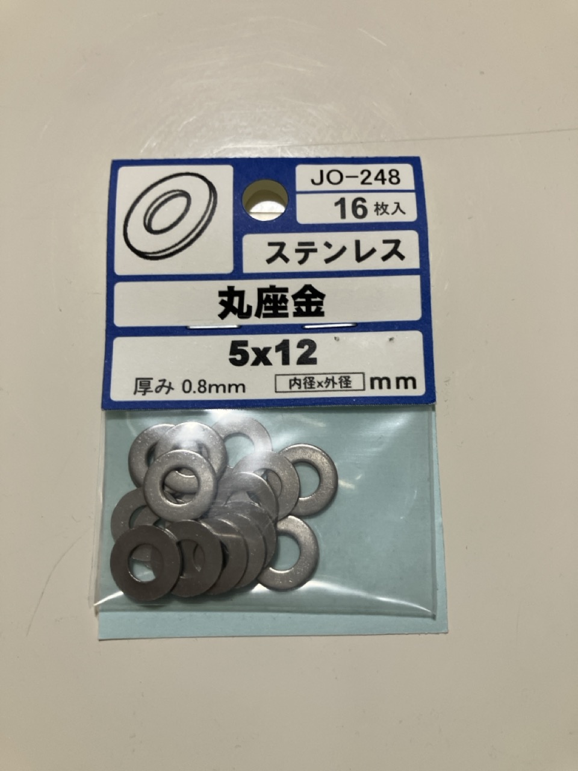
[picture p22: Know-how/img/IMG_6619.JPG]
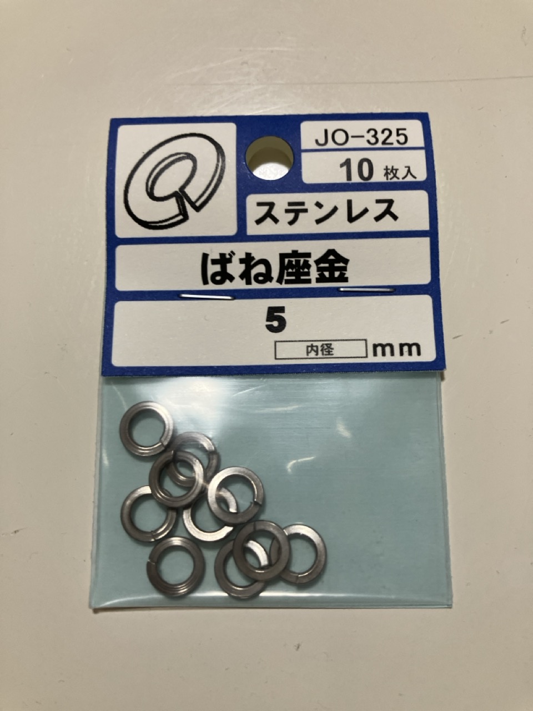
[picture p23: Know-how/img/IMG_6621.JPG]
　　　　

<br>

写真のように取り付けます。プレートなどへの取り付けが容易になります。

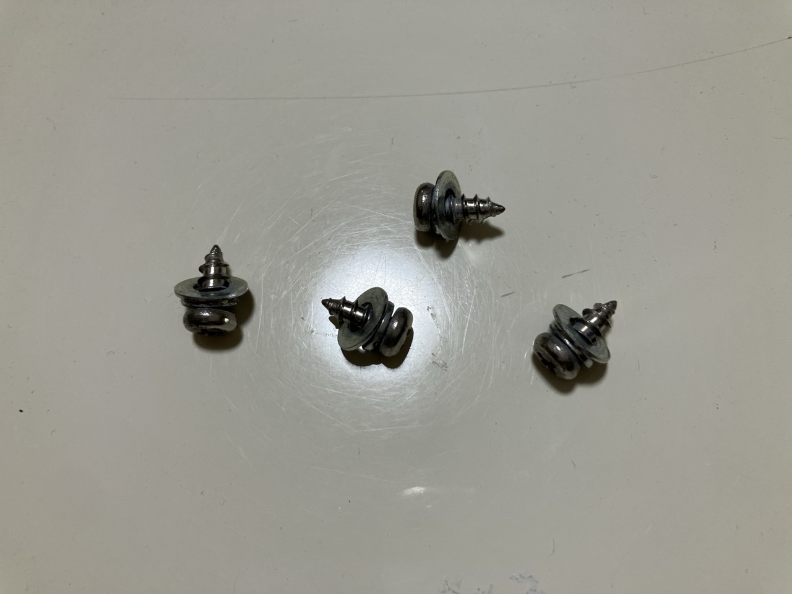
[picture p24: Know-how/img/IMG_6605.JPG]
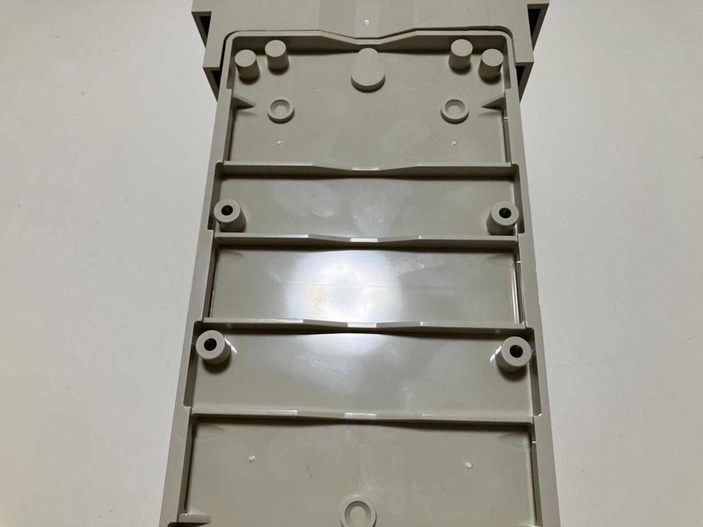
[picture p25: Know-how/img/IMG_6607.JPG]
　　

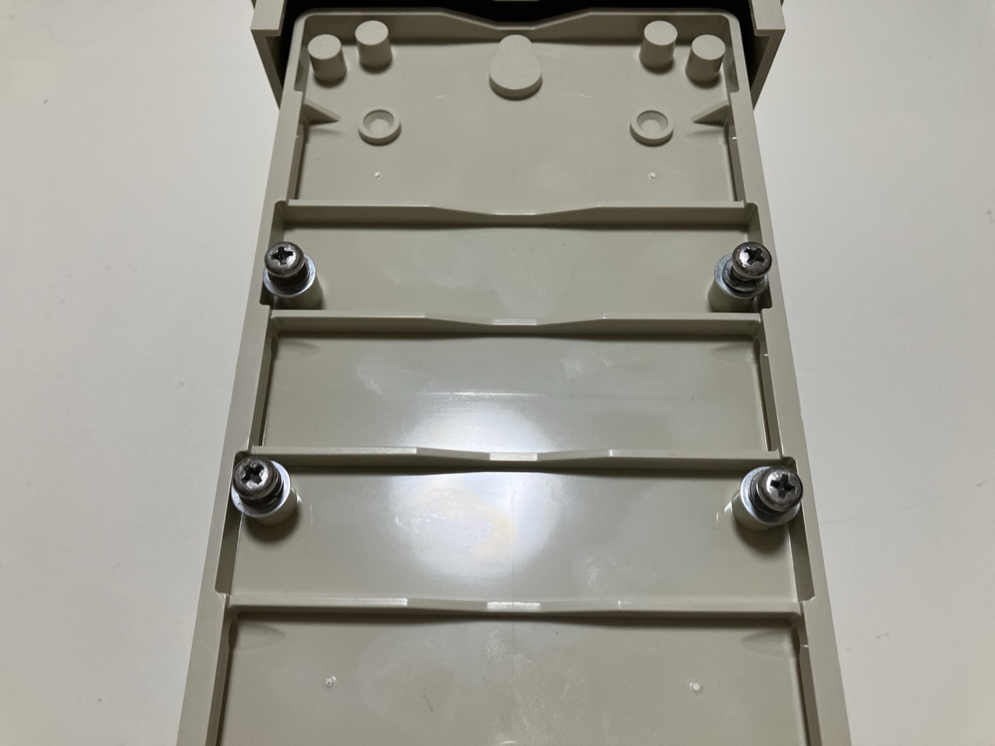
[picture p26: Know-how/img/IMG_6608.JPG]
　　

<br>

[戻る](https://github.com/maki-makirou/Measuring_Aquatic_Ultrasonic_Level_Instrument/tree/main)

<br>

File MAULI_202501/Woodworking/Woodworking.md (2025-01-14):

# 木工作業

[前へ](https://github.com/maki-makirou/Measuring_Aquatic_Ultrasonic_Level_Instrument/blob/main/MAULI_202501/Plastic_box/Plastic_box.md)　　[次へ](https://github.com/maki-makirou/Measuring_Aquatic_Ultrasonic_Level_Instrument/blob/main/MAULI_202501/MAULI_202501.md)

<br>

超音波センサーをプラボックスに取り付けるために木工作業を行います。

<br>



1. 市販品の板材（桧工作材　5x30x900）をノコギリで2つに切断して木工用ボンドで写真のとおり 5x60x450 に接着します。一晩置いて乾燥させてからノコギリで8cmの長さ（5x60x80）に切断してください。

<br>



2. ピン釘（20x13mm）を用意します。

<br>



3. プラボックス付属の木製プレートを取り出して桧工作材 5x60x450 との接着位置を確認してから、桧工作材に鉛筆等でピン釘を打つ場所に印を付けます。印を付ける位置は次の写真を参考にしてください。

<br>



4. プラボックス付属の木製プレートと桧工作材を木工用ボンドで接着してから金槌でピン釘を打ち込みます。

<br>



5. はみ出した木工用ボンドは水に濡らしたティッシュペーパーなどで拭き取ってください。

<br>

　　

6. ピン釘を金槌でバランス良く打ち込みます。

<br>



7. 一晩置いて木工用ボンドを乾燥させます。その後、プラボックス付属の木製プレートを元通りにプラボックスに取り付けてください。

<br>



8. ステンレス建具用木ねじ皿（2x19mm）を使ってプラボックス付属の木製プレートに液晶ディスプレイを固定します。

<br>



9. キリで予め穴を開けてからドライバーでステンレス建具用木ねじ皿（2x19mm）を4箇所に取り付けます。ラズパイpicoは写真上部の位置に仮置きすると作業がしやすいです。
液晶ディスプレイはプラボックス付属の木製プレートの取り外しができる位置に固定してください。固定金具が干渉しないよう少し下側に固定してください。

<br>

　　

10. 液晶ディスプレイの向かって右側は隙間が多くぐらつきやすいので、ビニルテープを丸めて枕を作ります。液晶ディスプレイの裏に詰めてぐらつかないようにしてください。

<br>

　　

11. ブレッドボードの裏の保護シートを剥がして写真の位置に貼り付けてください。

<br>



12. バッテリーを取り付けて正常に動くか確認します。

<br>

　　

13. USBのAタイプは裏表がわかりにくいのでシールでわかりやすくなるように工夫してみました。お好みでマーキングしてください。

<br>



14. 超音波センサーが写真の位置に来るようにセロハンテープで仮止めします。

<br>



15. 超音波センサーを貼り付ける位置に鉛筆等で印を付けます。

<br>

　　

16. 鉛筆で印を付けた四角形状の場所に接着剤を塗って超音波センサーを貼り付けます。

<br>

　　

17. 楊枝で超音波センサーを固定した後、セロハンテープで補強し一晩置きます。楊枝がなければ厚紙等で固定してください。

<br>



18. ピン釘（20x19mm）を用意してください。

<br>

　　

19. キリで予め穴を開けてからピン釘（20x19mm）を超音波センサーの四隅の穴に金槌で打ち込みます。少し長いので貫通して机等を傷つけないように厚めのものを敷いてから打ち込んでください。
先端が板から出てしまった場合はニッパーで切断してください。超音波センサーの裏に隙間ができるので前述のビニルテープで枕を作ってぐらつかないようにしてください。

<br>



20. プラボックスに組み込んで超音波センサーが正しい位置に来ているかを確認します。

<br>



21. バッテリーの裏側に両面テープを貼り付けてプラボックスの内側側面に貼り付けて固定してください。

<br>

　　

22. これで完成です！

<br>

[前へ](https://github.com/maki-makirou/Measuring_Aquatic_Ultrasonic_Level_Instrument/blob/main/MAULI_202501/Plastic_box/Plastic_box.md)　　[次へ](https://github.com/maki-makirou/Measuring_Aquatic_Ultrasonic_Level_Instrument/blob/main/MAULI_202501/MAULI_202501.md)

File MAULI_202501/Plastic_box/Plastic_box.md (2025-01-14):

# プラボックス加工

[前へ](https://github.com/maki-makirou/Measuring_Aquatic_Ultrasonic_Level_Instrument/blob/main/MAULI_202501/MAULI_202501.md)　　[次へ](https://github.com/maki-makirou/Measuring_Aquatic_Ultrasonic_Level_Instrument/blob/main/MAULI_202501/Woodworking/Woodworking.md)

<br>

まずプラボックスを加工します。

<br>



1. 本体と扉の接続部が分離しづらくなるようにジョイント部の穴に楊枝を金槌で打ち込みます。（私が考案した方法です。穴の使い方を間違っているかも？）

<br>



2. 打ち込んだ後、楊枝をニッパーでカットします。

<br>



3. 楊枝をカットした後の上側です。

<br>



4. カットした後の下側です。計4本必要です。

<br>



5. 超音波式距離センサーを嵌め込む箇所（写真の2箇所）をカッターやラジオペンチを使って取り除きます。

<br>

[前へ](https://github.com/maki-makirou/Measuring_Aquatic_Ultrasonic_Level_Instrument/blob/main/MAULI_202501/MAULI_202501.md)　　[次へ](https://github.com/maki-makirou/Measuring_Aquatic_Ultrasonic_Level_Instrument/blob/main/MAULI_202501/Woodworking/Woodworking.md)

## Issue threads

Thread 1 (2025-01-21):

Improper Input Validation

louwersj, 2025-01-21:
Temperature readings and distances are directly processed and used without validation. This could lead to unexpected behavior or errors if input is malformed or manipulated.

temp = get_temp()
ndist = get_dist(temp)

source link : https://github.com/maki-makirou/Measuring_Aquatic_Ultrasonic_Level_Instrument/blob/7346f4280f20a638dcab64a86076d955ce8b7e45/MAULI_202501/MAULI_20250113.py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

maki-makirou, 2025-01-22:
Thank you for your comment.
You are the first person to comment to me on GitHub!

I have never had such errors before during field observations, so I don't expect any major problems without fixing the code.
However, I have recently discovered that anomalous temperature sensor readings are also rare.
It may be due to individual differences in the PICO, but I will carefully check the readings and use them as a reference for future code modifications if necessary.
Thank you very much.

This is my first reply, I am not used to GitHub etiquette so please forgive me if I am rude.

louwersj, 2025-01-22:
I understand that you haven’t encountered these errors during field observations before, so it’s natural to feel like it might not be a pressing issue. However, rare conditions—like those occasional anomalous temperature readings—are a great example of why it can be valuable to validate sensor inputs.

Even if the issue is uncommon or specific to certain PICO devices, ensuring the code is robust enough to handle these edge cases now could save you time and frustration later. By addressing these potential anomalies proactively, you’re setting yourself up for smoother operations and making the system more reliable in the long run.

And no... you absolutely not rude... :-) Do note.. I just enjoy visiting random code every now and than and see if I could add something to the original developer to improve on it. Don't feel obligated to make any changes... just me giving some thoughts :-)

maki-makirou, 2025-01-23:
Thanks for the advice.
I write programs as a hobby, but I have an acquaintance who is a professional water level gauge programmer.
He said.” The important thing is not to write hard code. It's about writing code that never stops.”
Similar to your advice.
I have changed my perception.
Outdoor observation is a one-shot deal. I will make a stronger effort to write robust code in the future.
Thank you.

Closed 2025-01-23.

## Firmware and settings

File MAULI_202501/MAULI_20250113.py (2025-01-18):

"""
Measuring Aquatic Ultrasonic Level Instrument (MAULI)

    Author: maki-makirou
    License: MIT license
    URL: https://github.com/maki-makirou/Measuring_Aquatic_Ultrasonic_Level_Instrument
"""


### Parameter settings ###
# Program version
VERSION ='0.9.0'

## Start mode
# Time to display settings
NUM_DISPLAY = 20    # Unit: Number of times, Range: 1 to 40
# Time to display measurement settings
SET_DISPLAY_TIME = 4    # Unit: seconds, Range: 1 to 30
# Number of measured values displayed
DISPLAY_TIME = 2    # Unit: seconds, Range: 0.5 to 4

## Distance measurement mode
# Record start time after the power is turned on
RECORD_START_TIME = 60    # Unit: seconds, Range: 60 to 600
# Measurement interval at the time of log recording
INTERVAL_TIME = 60    # Unit: seconds, Range: 10 to 600
# Number of re-measurement at the time of abnormal value measurement
NUM_RETRY = 2    # Unit: Number of times, Range: 0 to 10
# Interval time of re-measurement
RETRY_TIME = 10    # Unit: seconds, Range: 1 to 10
# Time to light up led
LED_TIME = 0.05    # Unit: seconds, Range: 0 to 1
# Upper Limit value for re-measurement
UPPER_LIMIT = 0.2    # Unit: meter, Range: 0.1 to 1
# Lower Limit vue for re-measurement
LOWER_LIMIT = -0.2    # Unit: meter, Range: -0.1 to -1
# Turn on or turn off the power saving mode
POWER_SAVING_MODE = 1    # 0: OFF, 1: ON


### Main code　###
import utime, os
from machine import I2C, Pin, ADC, SPI
from pico_i2c_lcd import I2cLcd

start_time = utime.time()
trigger = Pin(0, Pin.OUT)
echo = Pin(1, Pin.IN)
led = Pin(25, Pin.OUT)
i2c = I2C(0, sda = Pin(16), scl = Pin(17), freq = 400000)
I2C_ADDR = i2c.scan()[0]
lcd = I2cLcd(i2c, I2C_ADDR, 2, 16)
lcd.putstr('Ver:' + str(VERSION) + '\n' + 'Interval:' + str(int(INTERVAL_TIME))+ 'sec')
utime.sleep(SET_DISPLAY_TIME)
lcd.clear()


def get_temp():
    sensor_temp = ADC(4)
    conversion_factor = 3.3 / (65535)
    reading = sensor_temp.read_u16() * conversion_factor
    # The temperature sensor measures the Vbe voltage of a biased bipolar diode, connected to the fifth ADC channel
    # Typically, Vbe = 0.706V at 27 degrees C, with a slope of -1.721mV (0.001721) per degree.
    temperature = 27 - (reading - 0.706)/0.001721
    return round(temperature, 2)


def get_dist(temp):
    trigger.low()
    utime.sleep_us(2)
    trigger.high()
    utime.sleep_us(10)
    trigger.low()
    while echo.value() == 0:
        signaloff = utime.ticks_us()
    while echo.value() == 1:
        signalon = utime.ticks_us()
    timepassed = signalon - signaloff
    distance = round(((timepassed / 1000000) * (331.50 + (0.606681 * temp)))/ 2, 3)
    return distance, timepassed


def display_LCD():
    temp = get_temp()
    lcd.putstr('Dist: ' + f'{get_dist(temp)[0]:.3f}' + ' m\n' + 'Temp: ' + f'{temp:.2f}' + ' ' + 'C')
    utime.sleep(DISPLAY_TIME)
    lcd.clear()


def csv_data_conv(i, time, distance, temperature, timepassed, retry):
    time_4 = f'{time[4]:02}'
    time_5 = f'{time[5]:02}'
    date_time = f'{time[0]}/{time[1]}/{time[2]} {time[3]}:{time_4}:{time_5}'
    output = f'{i},{date_time},{distance},{temperature},{timepassed},{retry if retry else ""}'
    return output


## Start mode
i = 1
while True:
    now_time = utime.time()
    if now_time - start_time <= RECORD_START_TIME - 7:
        if i <= NUM_DISPLAY:
            display_LCD()
            i += 1
    else:
        lcd.putstr('will start recording soon...')
        utime.sleep(4)
        lcd.clear()
        lcd.backlight_off()
        break
    utime.sleep(0.1)


## Distance measurement mode
with open('log.csv', 'a') as f:
    output = 'No,time,distance(m),temperature(c),timepassed(u_sec),retry'
    print(output, file=f)
    f.close()
    print(output)
i = 1
pre_dist = 0.0
while True:
    time = utime.localtime()
    now_time = utime.time()
    if (now_time - start_time) % INTERVAL_TIME == 0:
        led.value(1)
        utime.sleep(LED_TIME)
        led.value(0)
        max_dist = 0.0
        for retry in range(0, NUM_RETRY + 1):
            if retry > 0:
                if POWER_SAVING_MODE == 1: 
                    machine.lightsleep(int(RETRY_TIME * 1000) - 500)
                else:
                    utime.sleep(int(RETRY_TIME) - 0.5)
            temp = get_temp()
            dist = get_dist(temp)
            print('    ' + str(dist[0]))
            if retry == 0:
                max_dist = dist[0]
                max_temperature = temp
                max_timepassed = dist[1]
                if (dist[0] - pre_dist) >= UPPER_LIMIT or (dist[0] - pre_dist) <= LOWER_LIMIT:
                    pass
                else:
                    break
            else:
                if (dist[0] - max_dist) >= UPPER_LIMIT or (dist[0] - max_dist) <= LOWER_LIMIT:
                    if dist[0] > max_dist:
                        max_dist = dist[0]
                        max_temperature = temp
                        max_timepassed = dist[1]
                else:
                    if dist[0] > max_dist:
                        max_dist = dist[0]
                        max_temperature = temp
                        max_timepassed = dist[1]
                    break
        pre_dist = max_dist
        output = csv_data_conv(i, time, max_dist, max_temperature, max_timepassed, retry)
        with open('log.csv', 'a') as f:
            print(output, file=f)
            f.close()
            print(output)
        i += 1
        pre_dist = max_dist
        if POWER_SAVING_MODE == 1:        
            machine.lightsleep(int(((INTERVAL_TIME - (RETRY_TIME * retry)) * 1000) - 500))
        else:
            utime.sleep(((INTERVAL_TIME - (RETRY_TIME * retry))) - 0.5)
    utime.sleep(0.1)
    
    
    
